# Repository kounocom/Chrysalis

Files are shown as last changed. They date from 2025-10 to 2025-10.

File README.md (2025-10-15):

# Chrysalis

**A shield PCB for the nRF52840 Supermini/Pro Micro with an IMU, magnetometer, two buttons and a RGB LED, designed for nRF-based SlimeVR trackers**

## Overview

Chrysalis is a compact, back-mounted shield that solders directly to the underside of the nRF52840 Supermini or Pro Micro. It adds:

- 3-axis accelerometer/gyroscope (TDK InvenSense ICM-45686)  
- 3-axis magnetometer (QMC6309)  
- Two push-buttons for SW0 and RESET 
- Configurable RGB LED (Currently requires custom built firmware for changing the color)
- Pads for battery wires 

All exposed pads are marked with a star (`*`) and **must** be soldered.

## Requirements

- Assembled Chrysalis board
- nRF52840 Supermini or Pro Micro  
- Soldering iron (chisel or knife-type tip recommended), solder wire, flux (optional but recommended)

## Ordering Information

Chrysalis requires:
- Castellated holes on two sides  
- ENIG surface finish (for the QMC6309 BGA pads)  
- Thin PCB stack-up (0.8 mm or 1.0 mm recommended)

Manufacturing is most cost-effective at volume. For small quantities, consider ordering from [here](https://nekumori.pink/products/chysalis-v1_3).

## Hardware Assembly

1. **Prepare the Supermini**  
   - Update your bootloader **before** soldering and verify functionality. SWD pads will be covered after soldering, so unbricking/recovery will require removing the shield.  

2. **Align Chrysalis**  
   - Flip the Supermini upside-down (chips side down).  
   - Match the silkscreen markers on the backside of Chrysalis:  
     - **USB above** → near the USB connector 
     - **Antenna below** → near the antenna

3. **Solder Every Exposed Pad**  
   - All castellated pads are marked with `*`.  
   - Tack one corner pad to secure alignment, then solder the rest.  
   - Use direct solder connections—no wires or pin-headers.  
   - Inspect joints under magnification; check for cold or dry joints and bridges.

4. **Consider the Wire-Mod for the Pro-Micro Antenna**
   - https://docs.slimevr.dev/smol-slimes/hardware/smol-tracker.html#-copper-wire-for-wire-antenna-mod

## Pinout & Connections

| Supermini Pin | Signal |
|---|---|
| P0.17 | IMU INT1  |
| P0.24 | MISO |
| P0.06 | MOSI |
| P0.08 | SCK |
| P0.22 | CS |
| P1.00 | SW0 |
| RST / P0.18 | RESET |
| P0.20 | CLK_CTL |
| GND | GND |
| P0.31 | VCC |
| P0.02 | R |
| P1.15 | G |
| P0.29 | B |

> **Note:**  
> - The module intentionally sources power from one of the nRF52840's GPIOs (P0.31), as the voltage of it is adjustable.
> - The QMC6309 requires a minimum supply voltage of 2.5 V.

_For the complete schematic and up-to-date pin mapping, see `Chrysalis.kicad_sch`._

## Usage

1. Plug the assembled Supermini+Chrysalis combo into your host via USB.  
2. Flash the Slime-nRF Chrysalis firmware:   
   - Download the pre-compiled firmware:  
     https://docs.slimevr.dev/smol-slimes/firmware/smol-pre-compiled-firmware.html#pcb 
    - Follow the guide:  
     https://docs.slimevr.dev/smol-slimes/firmware/smol-flashing-firmware.html 
3. Open a serial console to verify IMU, magnetometer and button functionality.

> **Note:**  
> - At the time of writing this, the magnetometer will not be detected, because the IMU's sensorhub functionality has not been fully implemented.

## License

This project is licensed under the CERN Open Hardware Licence 2.0 – Strongly Reciprocal (CERN-OHL-S).  
See `LICENSE.md` for full terms

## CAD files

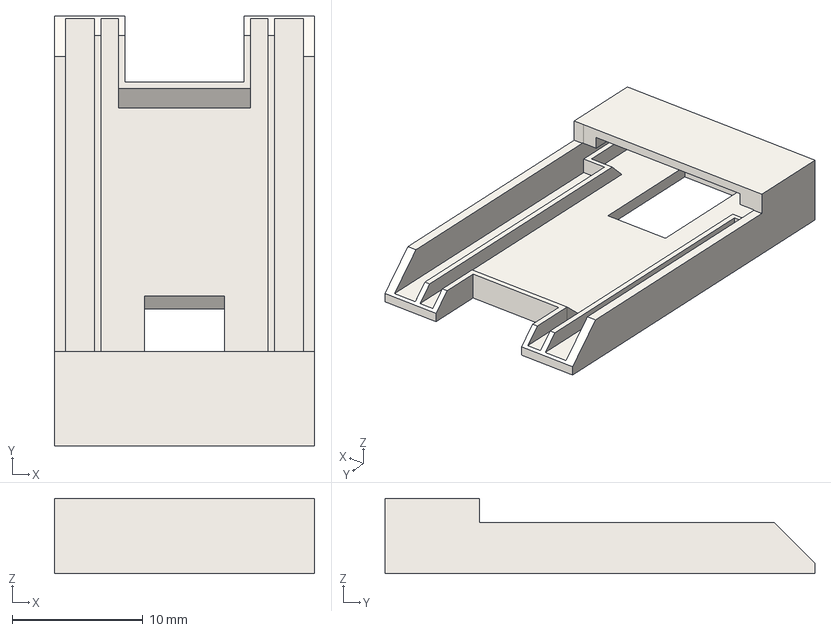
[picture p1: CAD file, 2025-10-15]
Chrysalis Data/Chrysalis Solder Helper/Chrysalis Solder Holder v12.step
19.9 x 32.8 x 5.75 mm

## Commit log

2025-10-15 Update to include Chrysalis Solder Helper Updated information
    [Bosch_LGA-14_3x2.5mm_P0.5mm.step, C_0402_1005Metric.step, C_0603_1608Metric.step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]
2025-10-15 Fix the Duplicated Files
    [Bosch_LGA-14_3x2.5mm_P0.5mm.step, C_0402_1005Metric.step, C_0603_1608Metric.step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]
